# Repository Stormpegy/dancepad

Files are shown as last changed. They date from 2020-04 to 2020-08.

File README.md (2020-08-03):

# Dancepad  
## note  
I'm releasing this build log early as i feel it's at a stage where it will be helpful to some people even with the missing information, no point keeping it hidden while i continue to slack on finishing it  

03-08-2020, lets see how long till the log actually gets finished

## Overview  
4 panel dance pad for DDR/ITG.  
I've been planning this project since 2017/2018 and never got anywhere until the covid pandemic of 2019/2020 hit, I'm glad to have finally made progress and gotten myself a playable dance pad.  

Before this project started I was passing ITG 13s and I've now pushed up to 14s and nearing the 15 range, it's certainly capable!    

Key features and goals of this project,  
- velostat sensors  
    - cheap  
    - adjustable sensitivity without the need to lift arrow panels  
- bracketless  
    - less parts
    - no need to source steel corner brackets from an arcade supplier  
- affordable build 
    - basic timber frame construction  
    - 3d printed parts  

The relatively simple timber frame with plywood base of this build along with using cheaper galvanised steel rather than stainless keeps the cost fairly low, the frame itself totaled $120aud.  
The panels are polycarbonate I got cut to size and drilled + countersunk them myself for a total of $80aud.  
The electronics for this dance pad are quite simple, with just a $10aud Arduino Leonardo clone from ebay, a sheet of velostat, some wires and a few basic connectors.  
Full cost table is WIP  

### This build log is split in to 4 sections.  

[Frame](https://github.com/Stormpegy/dancepad/tree/master/frame)   
[Panels](https://github.com/Stormpegy/dancepad/tree/master/panels)  
[Electronics](https://github.com/Stormpegy/dancepad/tree/master/electronics)  
[Bar](https://github.com/Stormpegy/dancepad/tree/master/bar)  

[Unfinished price breakdown](https://github.com/Stormpegy/dancepad/tree/master/Pricing.md)  

>full completed images go here one day  

Current state of the pad.  
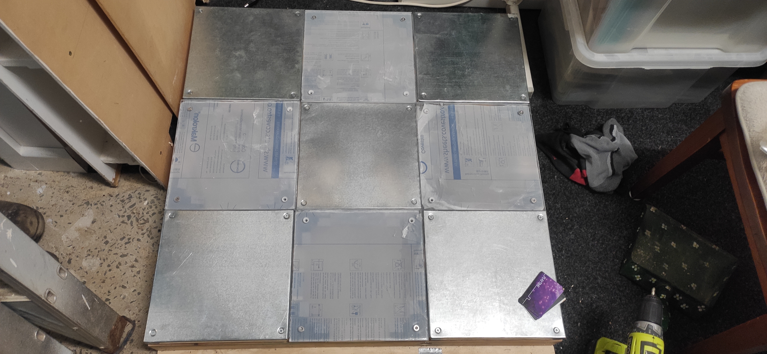
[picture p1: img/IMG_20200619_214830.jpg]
gamer


## Pad to do list  
- Chamfer all edges of the arrow panels  
- Obtain a bar and construct a mount for it  
- Disassemble the entire pad and paint the frame  
- Order arrow panel decals  
- Order v5 led strips for underneath the arrow panels  
- Construct an arcade thickness edging around the pad  

## Guide to do list  
- Finish electronics page
- Proof read everything  
- Ensure formatting is consistent  
- Ensure punctuation even exists  
- Pricing table  

## Changelog  
v0.2  
big update  
images moved to their own folder within each section to further reduce clutter  
panels readme.md started and nearly finished    
3d printed part links added, both .stl and .step  
made some more notes on what needs to be added to the frame page  

v0.1   
made all relevant folders  
moved images to relevant folders  
inital readme.md drafts  

## Other  
As with all my rhythm game related projects, huge thanks to the cons&stuff discord community, so much knowledge on any sort of homebuilt rhythm game controller you could ever want.  
https://consandstuff.github.io/  

Created by https://github.com/Stormpegy  
Feel free to contact me in the cons&stuff discord server under the same username.  

### License
Users are free to copy, modify, remix, redistribute this build log/guide however they like, feel free to modify in a way that suits you and even build pads based on this build log to sell if you wish, the only requirement is that I am credited and a link to my github is kept somewhere easily visible.

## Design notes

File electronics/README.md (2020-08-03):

>code is azle's velostat code he stole from wherever, try track down the original to credit it
>make more velostat sensors and take pics to write up a full tutorial  

# Electronics  
## Overview / schematic  

An Arduino leonardo r3 was chosen due to using an atmega32u4 which has full native usb support for high polling rates, and the standard arduino mounting is nice too.  
Other recommended boards are the Arduino micro, Sparkfun pro micro and teensy 2.0.  

Purchase what is readily available and suits you, my personal preference is a chinese Leonardo clone.  

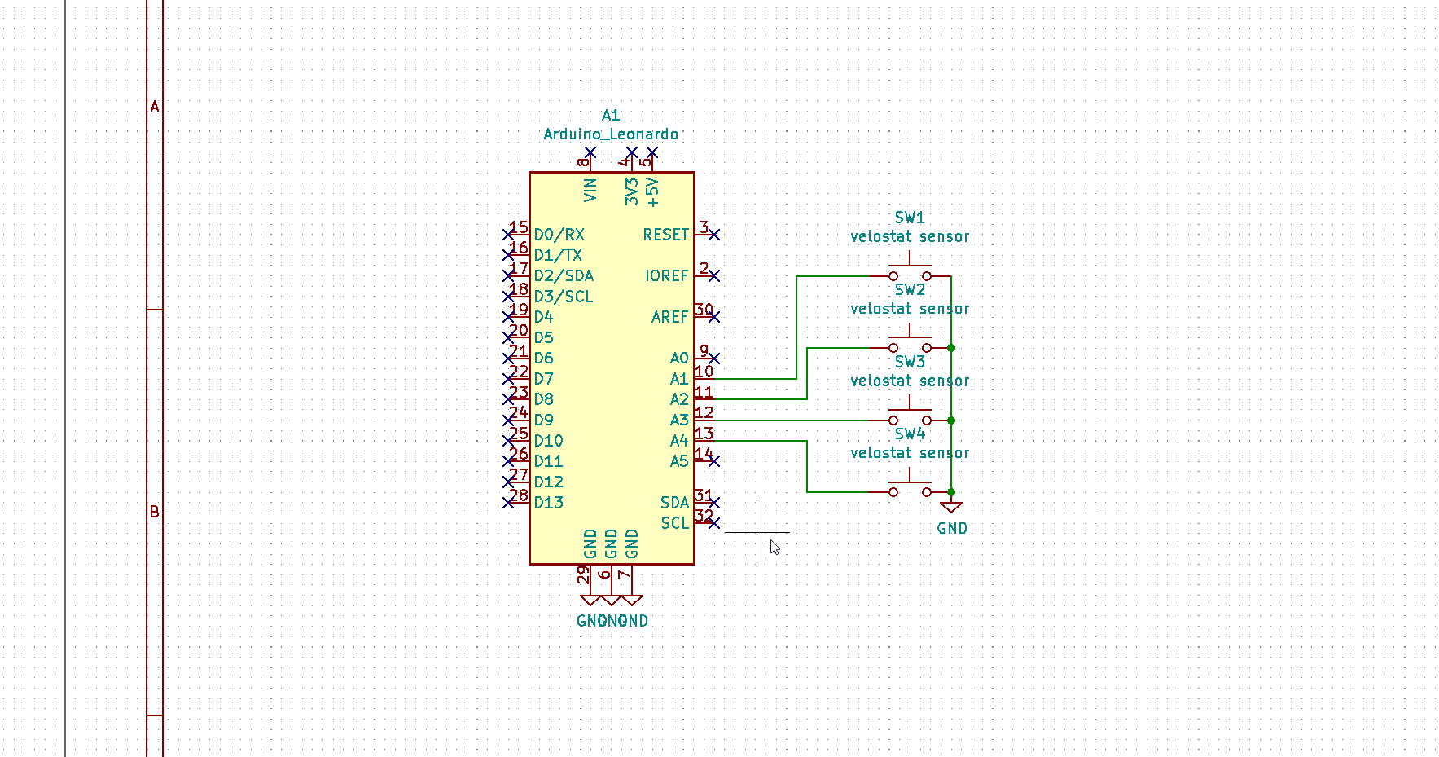
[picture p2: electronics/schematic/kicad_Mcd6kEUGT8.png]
Basic Schematic
  
(this will be updated along with the addition of LEDs at a later date)  

The wiring of the pad is quite simple, wired no different to if you were using arcade sensors, a common ground on all and a dedicated pin for each on the Arduino, in this case analog pins 1-4.  
>maybe find a schematic in staminanation of an fsr/velo setup using a voltage divider?  
>code stuff needs to be added

## Sensor construction  

| QTY | Part |
|-----|---|
| 1 | Standard 8.5cm x 5.4cm plastic card |
| 2 | 9-10cm strips of copper tape |
| 1 | 7.5cm x 1cm strip of velostat |
| 2 | 10cm-15cm~ lengths of 22-26 gauge copper wire |
| 1 | 2 pin male header 2.54mm spacing |
| | Masking tape |

To construct these sensors start by cutting your (preferably old/used) bank/arcade/loyalty card in half lengthways, and then laying a strip of copper tape along the middle, I've used 5mm wide copper tape but thicker is absolutely fine.  
You then will need to solder 1 of your lengths of wire on to the far end. 

Repeat so you have 2 identical pieces.  

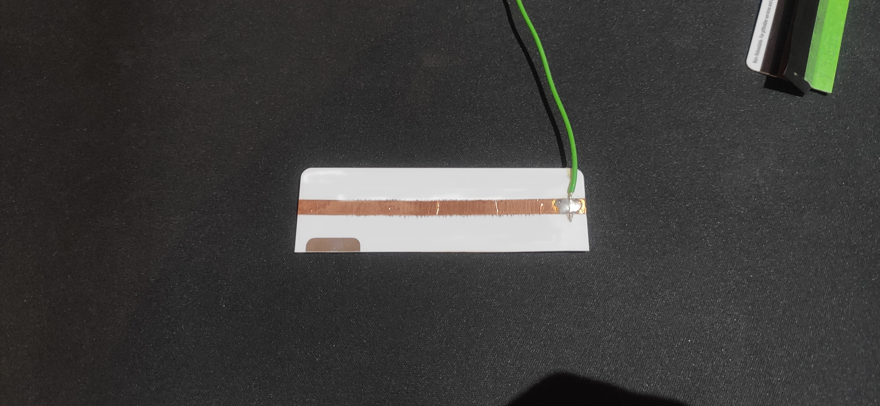
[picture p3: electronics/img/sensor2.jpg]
Sensor pic 2
  
You should end up with 2 pieces like this.  

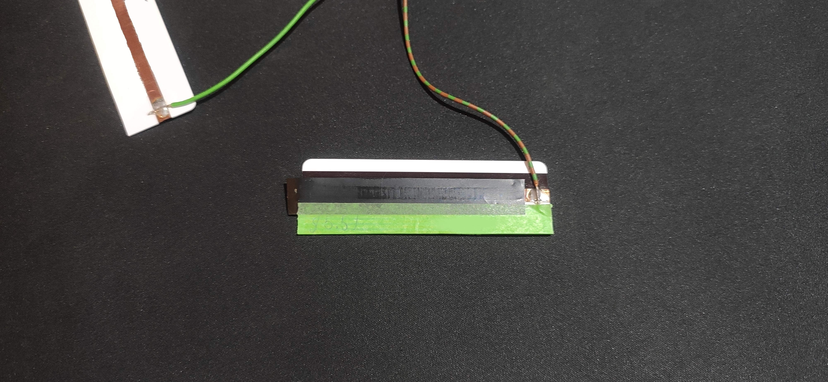
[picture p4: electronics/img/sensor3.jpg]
Sensor pic 3
  
Then lay your piece of velostat over the copper tape like this, ensure a few mm of overhang to prevent the copper tape on both halves being able to directly short.  
(try overlap the masking tape and velostat only by a few mm and avoid the masking tape overlapping the copper tape)  

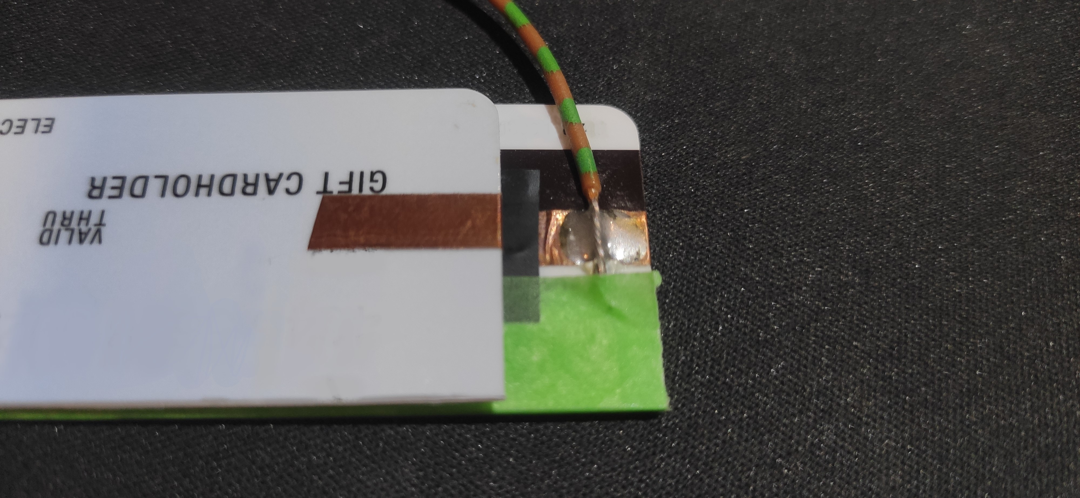
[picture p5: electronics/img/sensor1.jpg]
Sensor pic 1
  
Then place the second half of the sensor over the first half copper tape side down, ensuring a mm or two of velostat is exposed again just to reduce the chance of the copper tape just shorting directly to the other half and bypassing the velostat.  
Then lightly join both halves together with some more masking tape.  
>grab a finished sensor pic

Solder on 2 standard 2.54mm headers (or a connector of your choosing) to the other end of each wire and your sensor is done.  

## Wiring extensions  
> get a measurement of extension lengths  

I constructed 4 simple wiring extensions to run from each arrow panel to the Arduino.  
These are just lengths of wire with a male/female 2.54mm (0.1") header on each end.  

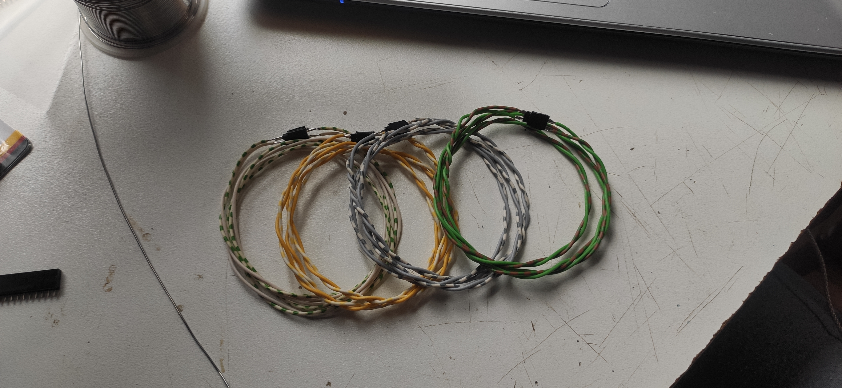
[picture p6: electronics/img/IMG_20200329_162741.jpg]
Extensions
  

I also later opted to route a length of old ethernet cable to underneath each arrow panel for future use with leds and possibly more sensors.  

[Bar](https://github.com/Stormpegy/dancepad/tree/master/bar)  
[Home](https://github.com/Stormpegy/dancepad)

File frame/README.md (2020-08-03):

# Frame  

## Frame build log  

The frame is based on arcade sizing, a 3x3 grid of 11" * 11" squares, resulting in a 33" * 33" or 838.2mm * 838.2mm square, excluding the area for mounting the bar.  
My frame is built entirely from 70mm * 45mm timber, then attatched to a 1.2m * 1.2m sheet of 12mm thick plywood.  
I figured the 90~mm height that comes with a more standard 2" * 4" or 90mm * 45mm wouldn't benifit the pad in anyway, though choose based on availability.  
Measurements will need to be changed if using timber not Xmm * 45mm.

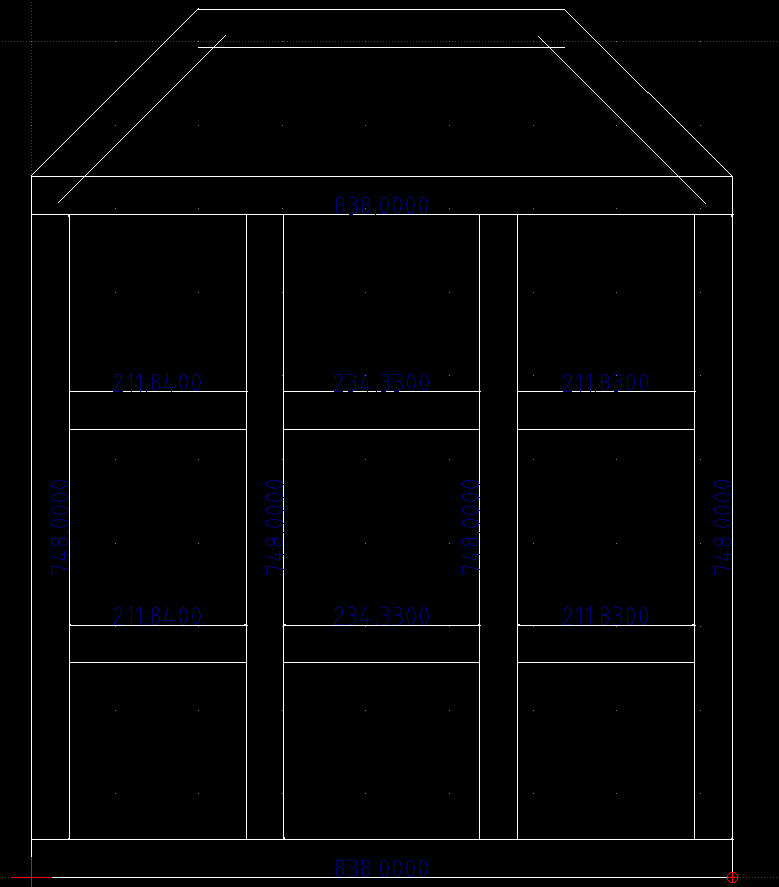
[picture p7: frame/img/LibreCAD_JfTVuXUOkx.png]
Frame dxf


Using these measurements we get the required lengths to build the base pad, excluding the area to the bottom for the bar.  
>This is somewhat dependant on your bar mounting system and as I'm playing chairmod until I can obtain my bar I've opted to leave this section out  
Alternatively you can ignore it all together and build just the pad itself  

| QTY | Length | 
|-----|---|
| 2 | 828mm |
| 4 | 748mm |
| 2 | 234mm |
| 4 | 212mm |  

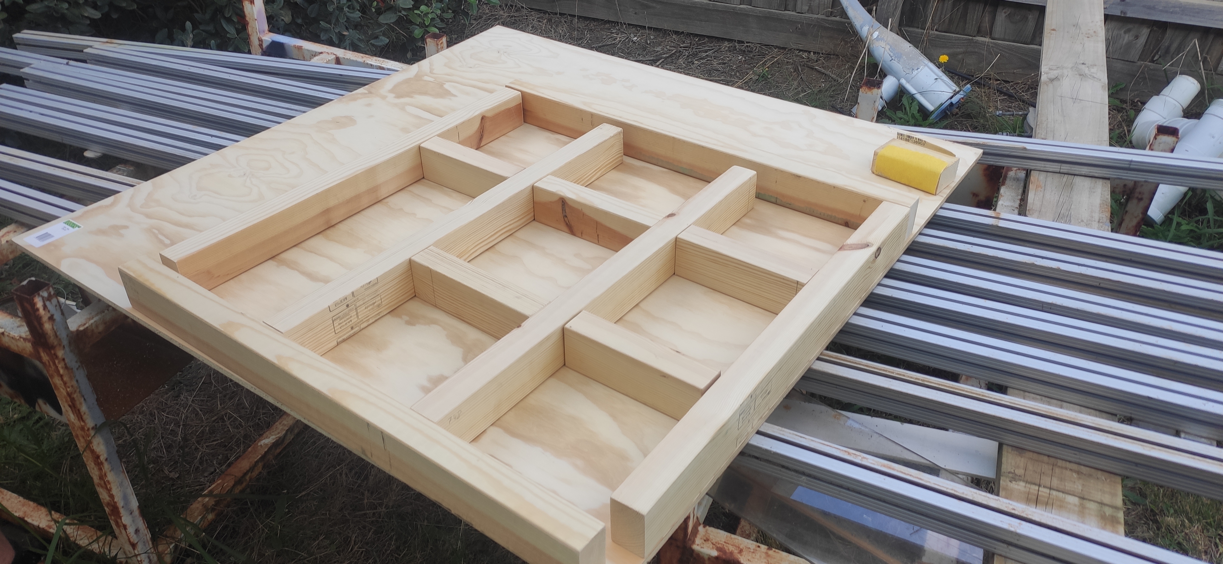
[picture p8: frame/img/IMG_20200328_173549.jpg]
Wood cut
  
All the lengths of wood cut and rough edges sanded down.  

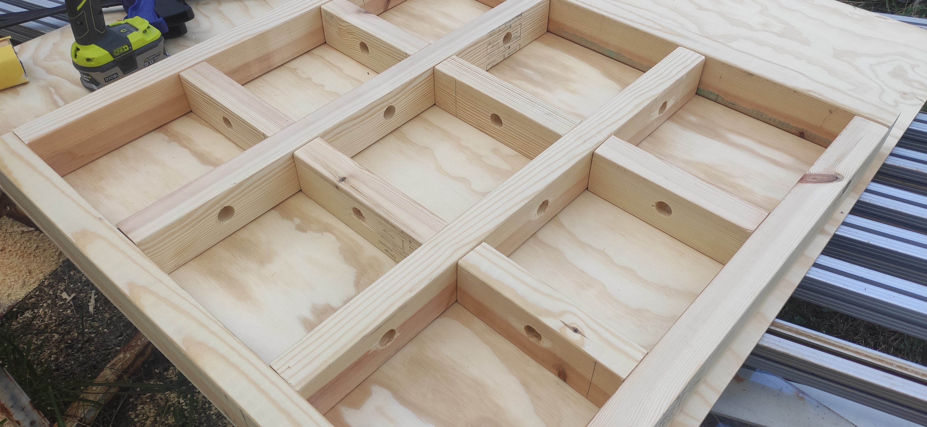
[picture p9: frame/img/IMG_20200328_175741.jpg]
Holes drilled
  
Drilled holes in all the inner pieces for cable routing using a 22mm spade bit.  
And a 25mm hole drilled at 140mm in from the outside edge, along one of the 838mm peices to mount the neutrik NAUSB-W connector.  

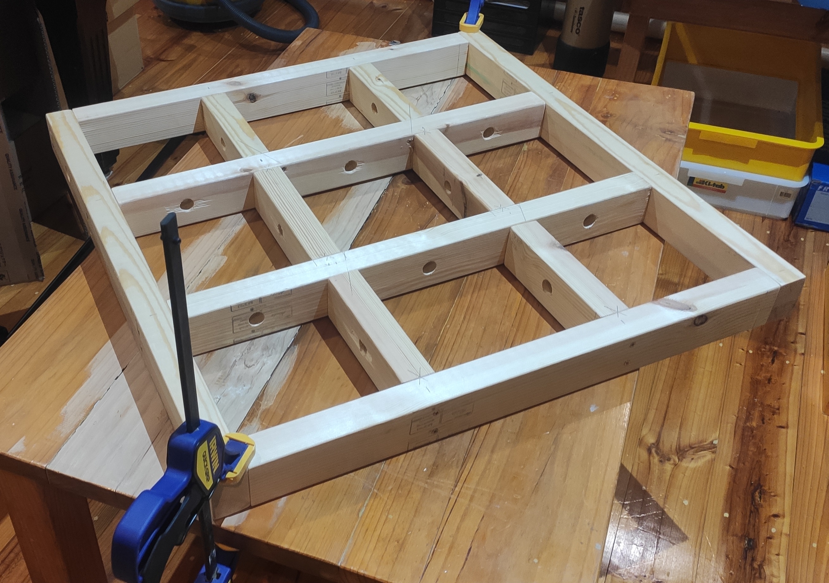
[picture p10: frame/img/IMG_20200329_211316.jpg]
Frame build
  

The frame itself was screwed and glued together using 10G x 100mm countersunk timber screws while taking care to ensure it was well aligned and square.  
>mention something to remind people to predrill for wood screws, and countersink  

>draw up an img of frame with screw locations  
  
Then screwed to the ply base using 60mm countersunk wood screws, these were quite a mix of various leftovers but worked out fine.  
You can see the screw placement here.  

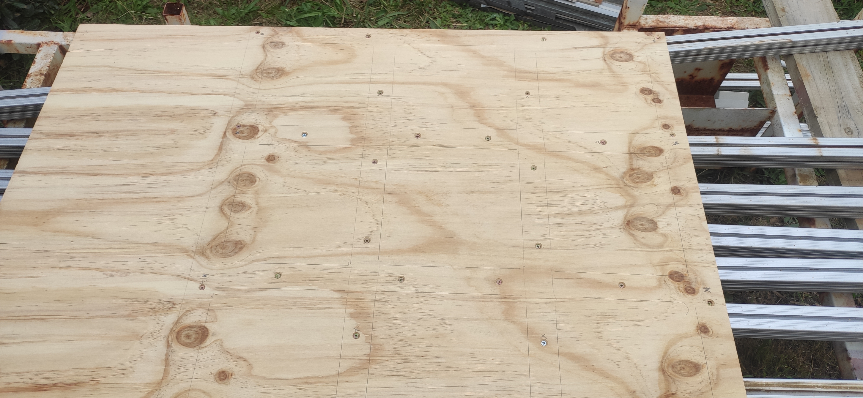
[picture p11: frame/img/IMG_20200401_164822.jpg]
Ply screws
  

>img trimming ply?  
>routing ply?  
>don't think i even have a photo for either of these two  

>will add bar area sizing / cuts at a later date  
 
[Panels](https://github.com/Stormpegy/dancepad/tree/master/panels)  
[Home](https://github.com/Stormpegy/dancepad)

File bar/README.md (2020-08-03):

# Bar  
WIP  

PIU bar will be used with a custom mounting bracket
this doc will contain the bar mounting dxf's / measurements and any other relevant information.  
I use a chair from the kitchen at the moment.....

[Home](https://github.com/Stormpegy/dancepad)

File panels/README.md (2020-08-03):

# Panels  

## Stationary panels  

Stationary panels are constructed from layers of leftover 12mm ply and some spare 6mm MDF I had around.  

I cut them all quite oversized to be milled down to 274mm x 274mm later, cut more accurately if you're going to be hand sanding these.  
(please wear a mask when working with MDF it's kinda yuck)  

Stationary panel pieces
These wooden panels were then glued together and clamped for a couple of days.  
Centre panel is 4x layers of MDF  
Outer panels are 1x ply 2x MDF  

Milling stationary panels

Stupid me didn't get a picture of bending the steel but the process was as follows.  

Place cut wood panel over steel square, clamp them together, flip over so the steel is on top, place large heavy object (steel block) on top near the edge I'm bending, gently hammer down to a 90* angle.  
I found a rubber mallet to be the most effective tool for this.  

Alternatively you can align the steel over the wooden panel and place another block of wood on top and clamp that all down as one, would be quite effective.    

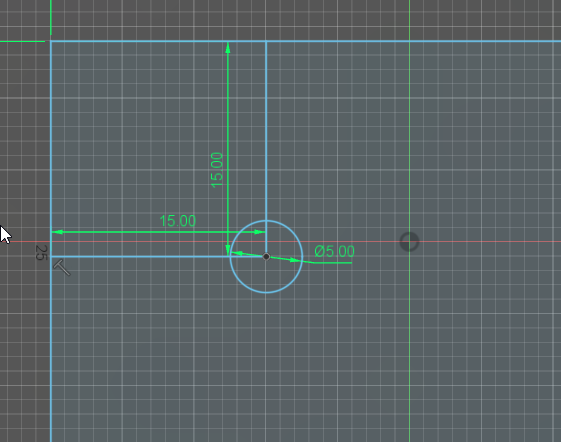
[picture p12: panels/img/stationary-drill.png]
Drill location
  

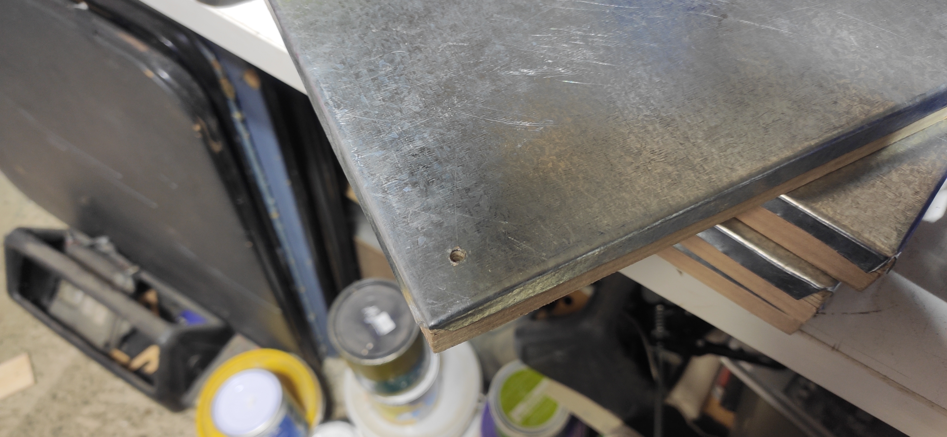
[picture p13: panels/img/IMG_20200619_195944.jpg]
Panels bent and drilled
  
I then drilled 5mm holes in each corner of the stationary panels, these are inset by about 15mm, it was not measured precisely.  
(! measure on the wooden panels !)

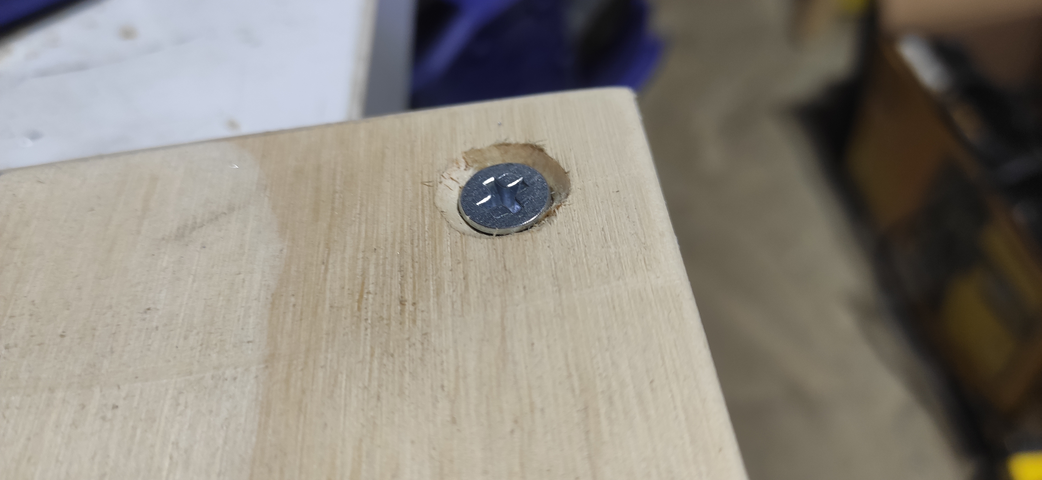
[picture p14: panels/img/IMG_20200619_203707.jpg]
Wood countersink
  
Top of wooden panels then countersunk quite deep.  

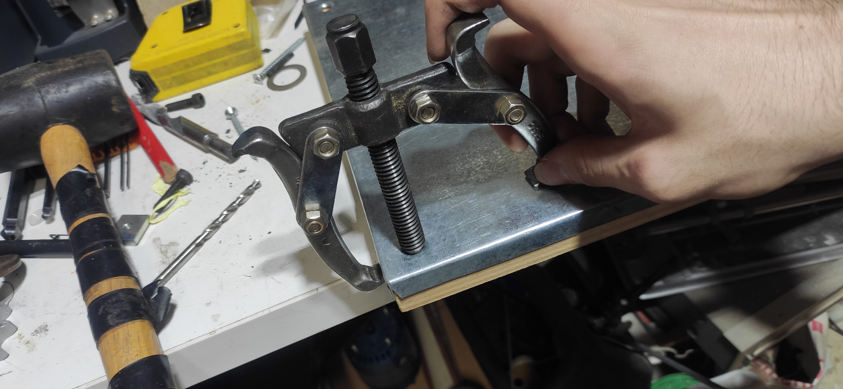
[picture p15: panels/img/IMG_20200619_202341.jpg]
Countersinking the metal
  
And the steel hammered to shape with a bearing puller, worked for the job tbh, a few heavy hits with the hammer and the screws sat flush.  
Test fitting screws on each hole and countersinking the wood / hammering more if needed to make them perfectly flush.  

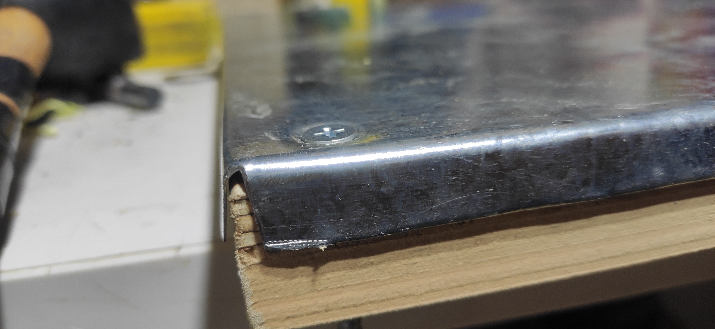
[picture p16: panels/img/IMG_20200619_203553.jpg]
Flush panels


Optionally the steel can be removed from the wood panels and with a hammer and a bit of work you can get a cleaner right angle on them, I didn't bother with this on many of them.  
Thats it for the stationary panels, on to the arrow panels  

## Arrow panels  

The Arrow panels are thankfully simpler than the stationary panels.  

(again this guide covers using PIU LX style bracketless arrow panels, if going for a bracketed pad all you need is the panels to be cut and you're done)  

After hunting around ebay and local classifieds websites I found a shop that specialized in showcase / display cabinets.  
I was able to get 4x 279mm x 279mm 10mm thick squares of polycarbonate cut for $80aud, all I had to do was drill and countersink them myself.  

Again I used the milling machine for this, as I don't own a drill press, polycarbonate is quite strong so you should be able to drill it with just a battery drill without fear of cracking.  

>something about dj505's alignment jig / measurements of hole location here  

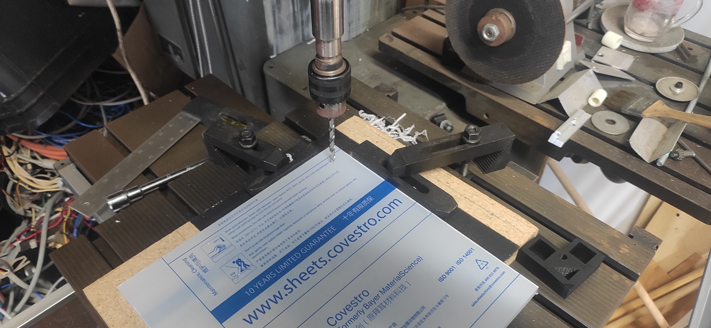
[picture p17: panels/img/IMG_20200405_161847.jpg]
Drilling panels
  
Panels being drilled to 6.5mm.  
(requires fairly precise alignment of the corner brackets, might drill them out to 7mm)

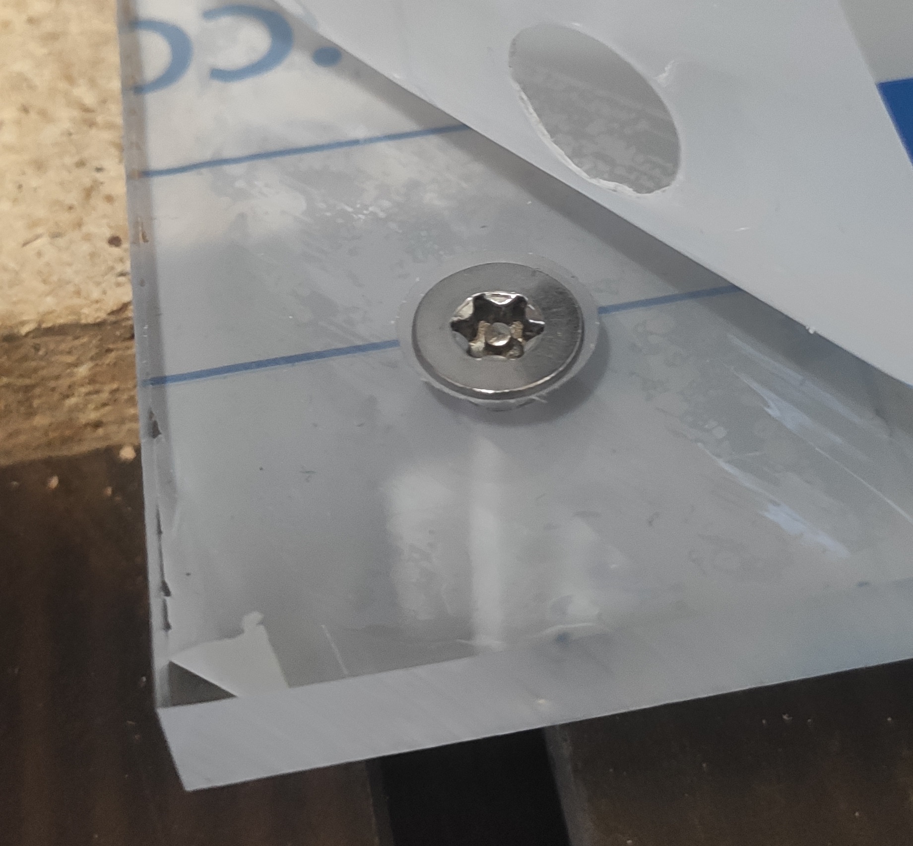
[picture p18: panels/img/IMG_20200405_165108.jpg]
Countersunk panels
  
Then countersink till the bolts are flush.  

### Arrow Decals  
WIP, yet to order decals, this part of the guide will remain unfinished for a while.  

## 3D Printed corner brackets and sensor mounts

### Corner brackets  

[Corner bracket .step](https://github.com/Stormpegy/dancepad/tree/master/panels/3d-files/corner-block-v9.step)  
[Corner bracket .stl](https://github.com/Stormpegy/dancepad/tree/master/panels/3d-files/corner-block-v9.stl)  

The corner brackets are designed to have an M6 nut glued in and then screwed in to the frame, with 2x 8G x 25mm wood screws, a total of 16 brackets needed for a single pad.  
(The outer corner hole was left in from the first version of this bracket, I found its use to not be required)

Though also consider,  
- [dj505's PIU C frame clones](https://www.thingiverse.com/thing:3973422)  
- [Mdigibou universal bracketless frames](https://www.thingiverse.com/thing:4389101)
- [Official Andamiro PIU C frames](https://www.arcadespareparts.com/andamiro_spare_parts/andamiro_parts_aput0ass011_switch_frame_c.html)  
(these are likely available from a number of stores, I've linked ASP as they're a known reputable seller)  

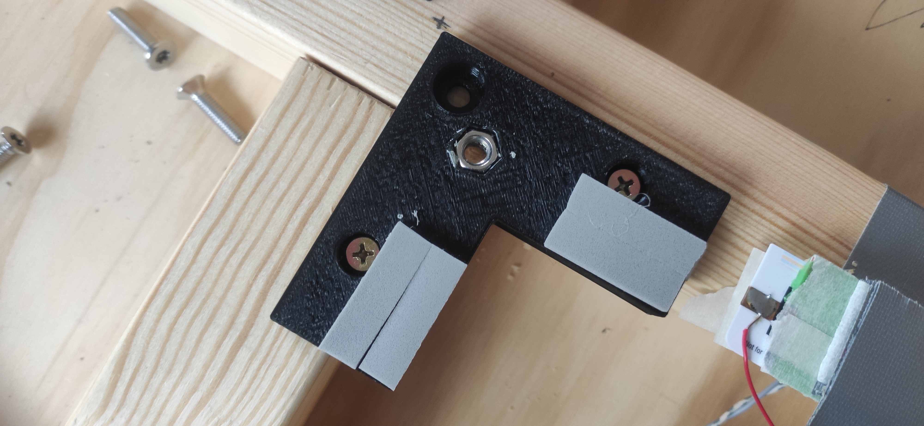
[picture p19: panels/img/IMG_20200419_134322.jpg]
Corner bracket installed
  
Corner bracket installed with M6 nut glued in and some foam tape applied for a little dampening.  

I would recommend lining up stationary panels and corner brackets at the same time to get everything as straight as you can.  
(Note the corner brackets do not sit against stationary panels)

### Sensor mount  
Sensor mount design is still a WIP, refining it and sorting print settings.  

[Sensor mount .step](https://github.com/Stormpegy/dancepad/tree/master/panels/3d-files/sensor-mount-v1.step)  
[Sensor mount .stl](https://github.com/Stormpegy/dancepad/tree/master/panels/3d-files/sensor-mount-v1.stl)  

Sensor mounts are currently a work in progress and so is this section.  

Sensor mounts designed to hold plastic card based velostat sensors, they're 9cm x 2cm and screw down with the same 8G x 25mm wood screws.  

Personally I attatch my sensors with a small loop of duct tape, it's firm enough to hold them but still easily removable.  

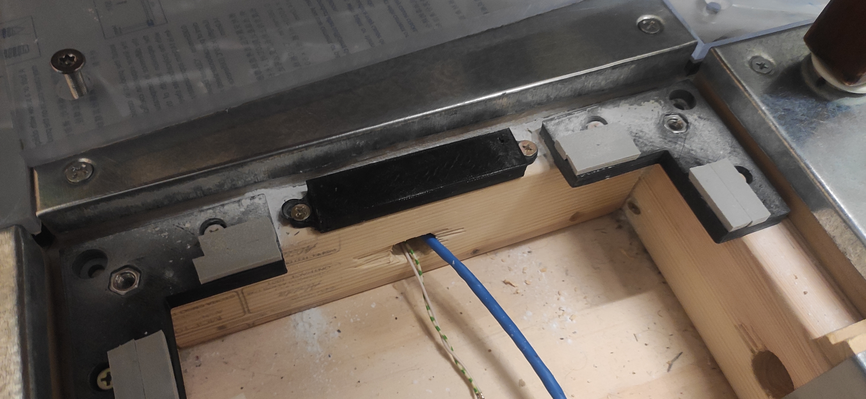
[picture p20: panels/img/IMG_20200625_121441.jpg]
Sensor mount v1
 

This design could also work well for FSR's, if wanting to use traditional arcade sensors I recommend checking out-  
- [BlueMoonMystic's X2 raw thrills sensor channel](https://www.thingiverse.com/thing:4547247)
- [Mdigibou universal bracketless frames](https://www.thingiverse.com/thing:4389101)
- SpaghettiSnail's sensor channel, found in the C&S discord #dancepad

Ready for the electronics now!  
[Electronics](https://github.com/Stormpegy/dancepad/tree/master/electronics)  
[Home](https://github.com/Stormpegy/dancepad)

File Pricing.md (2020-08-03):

# Price breakdown
| | | |
All prices in AUD and 'accurate' at time of purchase.  
highly unfinished page  
prices with ~ are guesstimates

### Frame
| QTY | Part | Price |
|-----|---|-----|
| 1 | 1200x1200 12mm ply sheet| $30.85 |
| 3 | 2.4m 70x45mm pine | $26.43 |
| | total | $57.28 |

### Panels  
| QTY | Part | Price |
|-----|---|-----|
| 4 | 279x279mm 9.5mm polycarbonate panel| $80.00 |
| 1 | 1200x600 0.55 galvabond steel | $34.10 |
| 2 | M6 x 25 S-Torx countersunk bolt 8 pack | $14 |
| | total | $128.1 |
please note the mdf used for the stationary panels is not yet accounted for, probably +$30~

### Electronics  
| QTY | Part | Price |
|-----|---|-----|
| 1 | Arduino Leonardo clone | $15 |
| 1 | Velostat/Linqstat sheet | $19.95 |
| 1 | Neutrik NAUSB-W-B| $19.80 |
| 1 | 5mm Copper tape | $10~ |
| 1 | 2.54mm Pitch headers (40pin male+female kit) | $5 |
|  | 22-26g Copper wire | $10~ |
| 1 | Perfboard / Universal prototype pcb | $5~ |
| 1 | 20cm micro usb cable | $7 |
| | total | $91.75 |

estimate amount of 6mm MDF used  
estimate wire length used  
get screw prices
10G x 60m  
8G x 25mm  
10G x 100mm  
foam weather stripping  
3D printed parts estimate  
pva based wood glue

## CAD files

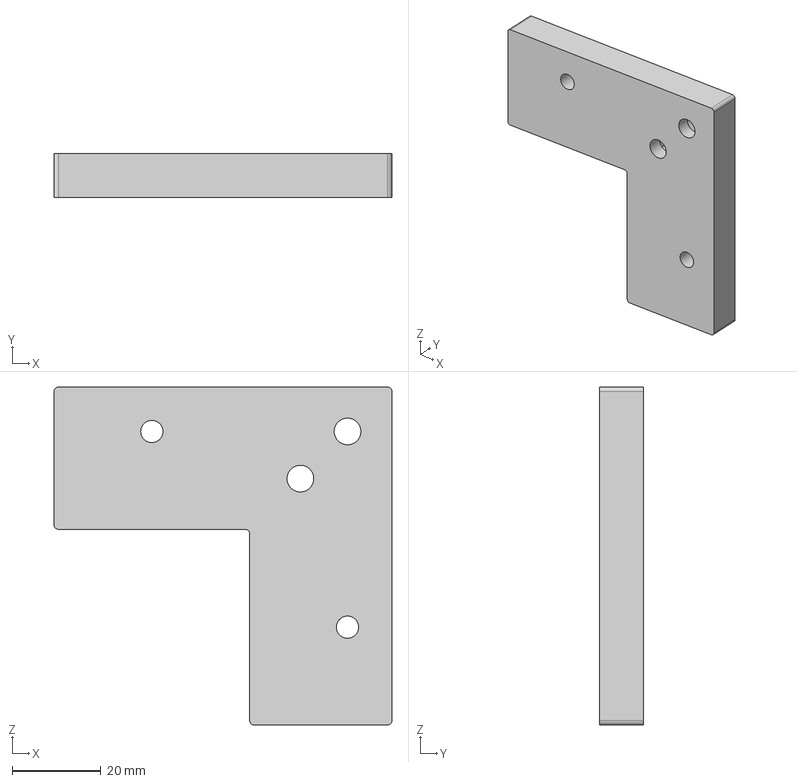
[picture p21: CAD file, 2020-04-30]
panels/3d-files/corner-block-v9.step
76.0 x 10.0 x 76.0 mm

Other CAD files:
panels/3d-files/sensor-mount-v1.step
panels/3d-files/corner-block-v9.stl
panels/3d-files/sensor-mount-v1.stl

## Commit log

2020-04-30 inital commit
    v2
    restarted the repo to clean up stuff
    [cornerblock v9.step, cornerblock v9.stl]
2020-06-22 v0.2
    read changelog in main readme
    [corner-block-v9.step, corner-block-v9.stl, cornerblock v9.step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]
2020-06-23 small update
    quick little update on electronics + frame pages
